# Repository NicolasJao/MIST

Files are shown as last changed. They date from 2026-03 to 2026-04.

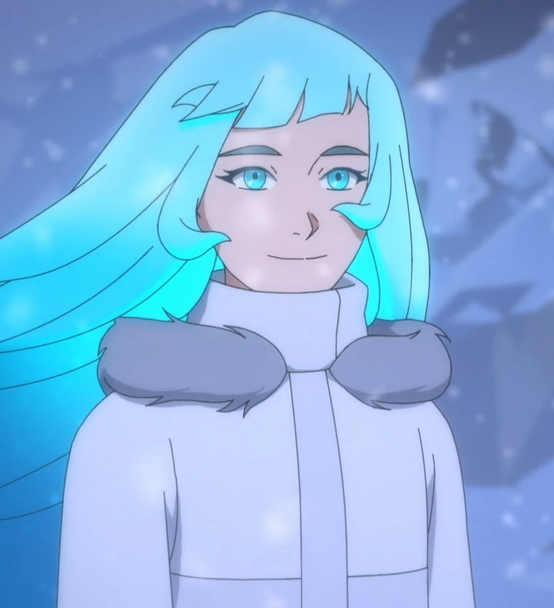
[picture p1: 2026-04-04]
RESOURCES/IMAGES/SILKSCREEN/MIST CI.png

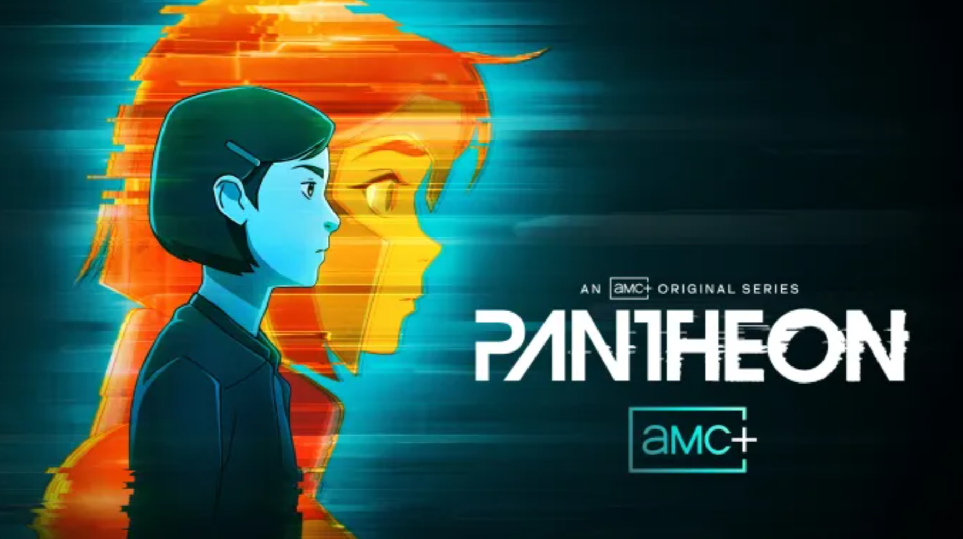
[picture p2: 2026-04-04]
RESOURCES/IMAGES/SILKSCREEN/Pantheon.png

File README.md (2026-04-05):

# MIST
4ES3 L02

Final project of SMRTTECH 4ES3 course.

A PCB project. Has an LED matrix that lights up in patterns based on music input from a microphone. Can make robot faces that makes expressions. Made with KiCad v9.0.

See /RESOURCES/IMAGES/3D VIEWER to see images of the PCB.
See /CODE to see the programming of the PCB.

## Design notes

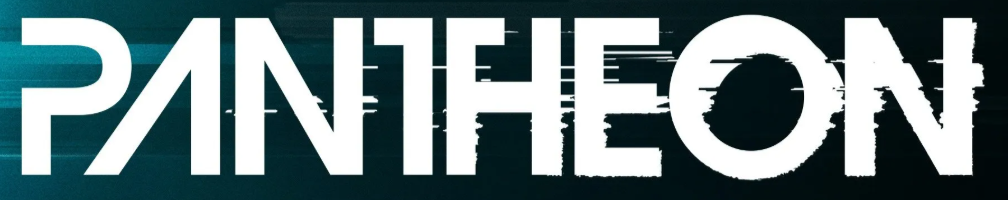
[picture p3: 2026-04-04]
RESOURCES/IMAGES/SILKSCREEN/Pantheon show.png

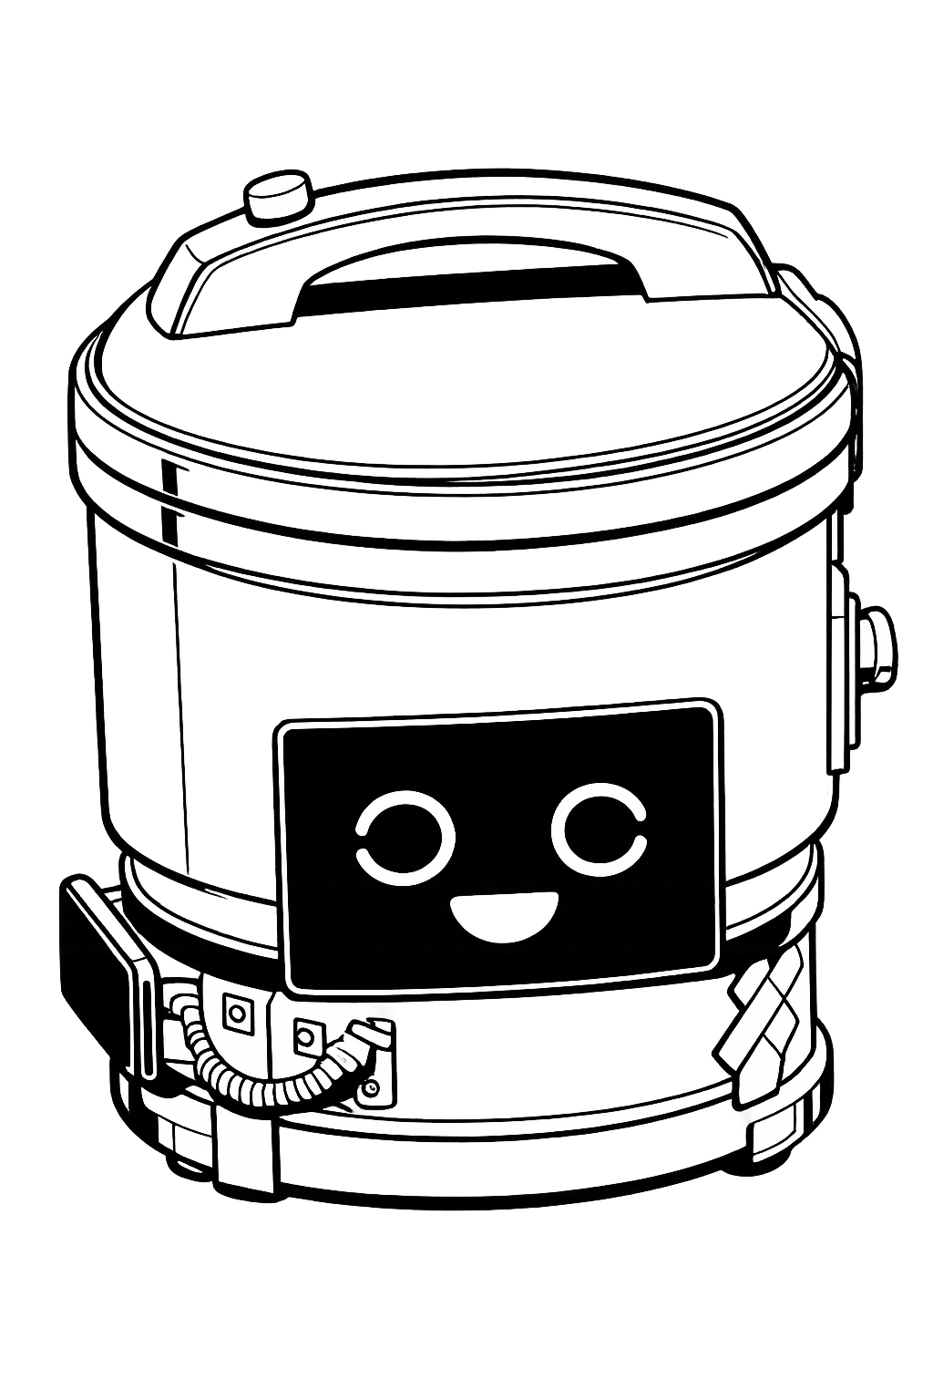
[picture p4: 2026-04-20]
RESOURCES/IMAGES/SILKSCREEN/MIST happy bitmap.png

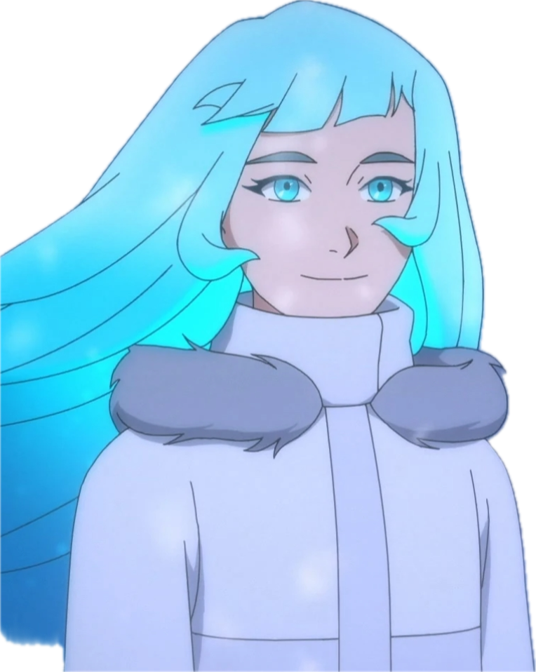
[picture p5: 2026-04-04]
RESOURCES/IMAGES/SILKSCREEN/MIST CI cropped.png

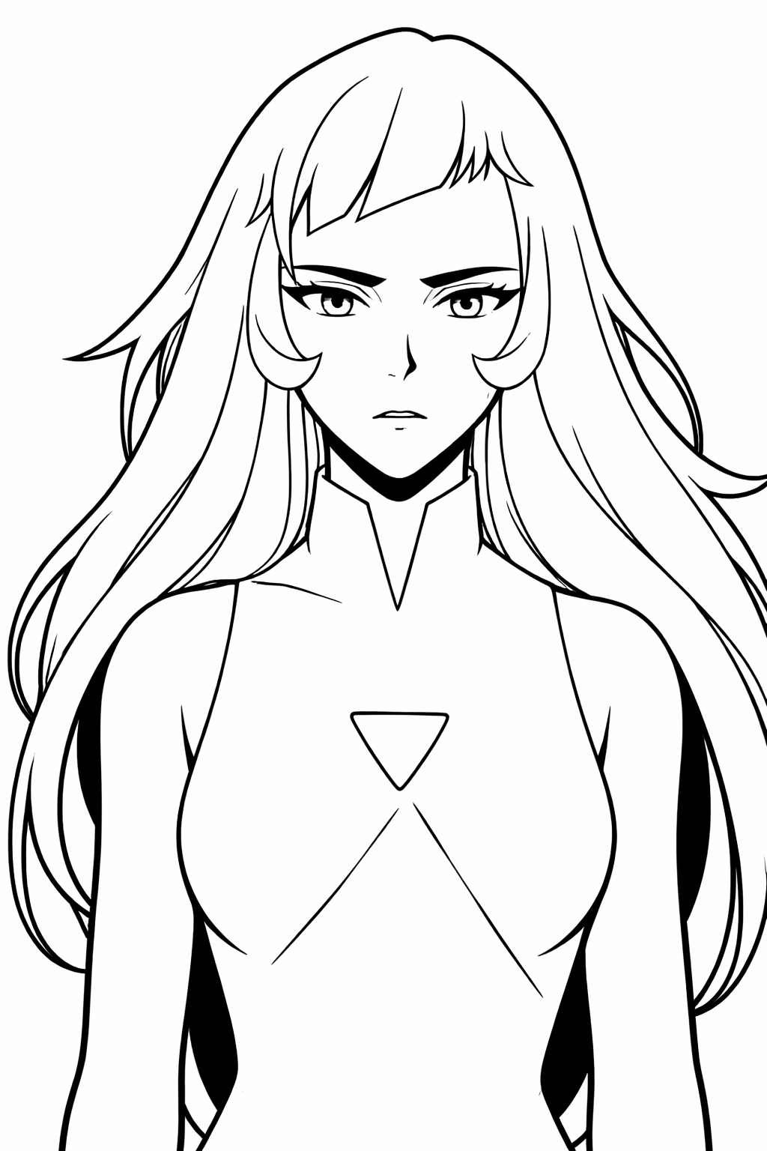
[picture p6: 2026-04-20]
RESOURCES/IMAGES/SILKSCREEN/MIST CI 2 bitmap.png

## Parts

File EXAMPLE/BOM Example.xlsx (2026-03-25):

Bill Of Material - Project Template
Item # | Designator | Description / Value | Manufacturer | Mounting Type | Package / Case | Unit Price | Quantity | Total | Link
1 | U1 | AtMega328PU | Atmel | SMT | 32-TQFP | $2.51 | 1 | $2.51 | https://www.digikey.ca/en/products/detail/microchip-technology/ATMEGA328PB-AU/5638812
2 | C1, C2 | 100nF Ceramic Capacitor | KEMET | SMT | 0805 (2012 Metric) | $0.26 | 2 | $0.52 | https://www.digikey.ca/en/products/detail/kemet/C0805C104J5RACAUTO/3314435
3 | C3, C4 | 22pF Ceramic Capacitor | Murata Electronics | SMT | 0805 (2012 Metric) | $0.35 | 2 | $0.70 | https://www.digikey.ca/en/products/detail/murata-electronics/GRM21A5C2D220JW01D/6606256
4 | C5 | 22uF Ceramic Capacitor | Murata Electronics | SMT | 0805 (2012 Metric) | $0.45 | 1 | $0.45 | https://www.digikey.ca/en/products/detail/murata-electronics/GRM21BZ70J226ME44K/19560602
5 | Y1 | 16Mhz Crystal Osillator | Abracon LLC | SMT | 4-SMD (3.2x2.5) | $1.05 | 1 | $1.05 | https://www.digikey.ca/en/products/detail/abracon-llc/ABM8-16.000MHZ-B2X-T/12349981
6 | R1, R2 | 10k Resistor | Würth Elektronik | SMT | 1206 (3216 Metric) | $0.29 | 2 | $0.58 | https://www.digikey.ca/en/products/detail/bourns-inc/CRM1206AJW-103ELF/8258196
7 | R3, R4, R5 | 220 Resistor | Bourns | SMT | 1206 (3216 Metric) | $0.18 | 3 | $0.54 | https://www.digikey.ca/en/products/detail/w-rth-elektronik/560112132015/24849722
8 | R6, R7 | 5.1K Resistor | Littlefuse | SMT | 1206 (3216 Metric) | $0.15 | 2 | $0.30 | https://www.digikey.ca/en/products/detail/bourns-inc/CR1206-JW-512ELF/3925471
9 | TH1 | 10K Thermoistor | YOCERA AVX | SMT | 1206 (3216 Metric) | $1.40 | 1 | $1.40 | https://www.digikey.ca/en/products/detail/littelfuse-inc./LR103G0J/3046801
10 | D1 | RGB LED | Kingbright | THT | 5MM LED | $0.99 | 1 | $0.99 | https://www.digikey.ca/en/products/detail/kingbright/WP154A4SUREQBFZGC/3084119
11 | J2 | USB Type C Power Only | Same Sky | SMT |  | $0.59 | 1 | $0.59 | https://www.digikey.ca/en/products/detail/same-sky-formerly-cui-devices/UJC-H-G-SMT-P6-TR/24818614
12 | S1 | Tactile Switch | Alpine | SMT |  | $0.32 | 1 | $0.32 | https://www.digikey.ca/en/products/detail/alps-alpine/SKRPABE010/18768948
 |  |  |  |  |  |  | Total: | $9.95

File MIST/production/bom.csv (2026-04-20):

Designator | Footprint | Quantity | Value | LCSC Part #
C1, C2 | 0805 | 2 | 100n
C3, C4 | 0805 | 2 | 22pF
C5 | 0805 | 1 | 22uF
C6, C8, C9 | 0805 | 3 | 0.1u
C7 | 0805 | 1 | 0.1n
J1, J2 | PinHeader_1x08_P2.54mm_Vertical | 2 | Conn_01x08
J3 | USB_C_Receptacle_GCT_USB4125-xx-x_6P_TopMnt_Horizontal | 1 | USB_C_Receptacle_PowerOnly_6P
J4 | PinHeader_2x03_P2.54mm_Vertical | 1 | ICSP
MK1 | CUI_CMC-5042PF-AC | 1 | CMC-5042PF-AC
R1, R2, R3 | 0805 | 3 | 10k
R10 | 0805 | 1 | 100k
R4, R5 | 0805 | 2 | 5.1k
R6, R7 | 0805 | 2 | 2k
R8, R9 | 0805 | 2 | 1M
S1, S2 | SW_SKRPABE010 | 2 | SKRPABE010
U1 | TQFP-32_7x7mm_P0.8mm | 1 | ATmega328PB-A
U2 | SOIC-24W_7.5x15.4mm_P1.27mm | 1 | MAX7219
U3 | SOT65P210X110-5N | 1 | MAX4466EXK
Y1 | Crystal_SMD_3225-4Pin_3.2x2.5mm | 1 | 16 Mhz Crystal

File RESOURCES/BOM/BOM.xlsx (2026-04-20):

Bill Of Material - Project Template
Item # | Designator | Description / Value | Manufacturer | Mounting Type | Package / Case | Unit Price | Quantity | Total | Link
1 | U1 | AtMega328PB | Atmel | SMT | 32-TQFP | $2.51 | 1 | $2.51 | https://www.digikey.ca/en/products/detail/microchip-technology/ATMEGA328PB-AU/5638812
2 | C1, C2 | 100nF Ceramic Capacitor | KEMET | SMT | 0805 (2012 Metric) | $0.26 | 2 | $0.52 | https://www.digikey.ca/en/products/detail/kemet/C0805C104J5RACAUTO/3314435
3 | C3, C4 | 22pF Ceramic Capacitor | Murata Electronics | SMT | 0805 (2012 Metric) | $0.35 | 2 | $0.70 | https://www.digikey.ca/en/products/detail/murata-electronics/GRM21A5C2D220JW01D/6606256
4 | C5 | 22uF Ceramic Capacitor | Murata Electronics | SMT | 0805 (2012 Metric) | $0.45 | 1 | $0.45 | https://www.digikey.ca/en/products/detail/murata-electronics/GRM21BZ70J226ME44K/19560602
5 | Y1 | 16Mhz Crystal Osillator | Abracon LLC | SMT | 4-SMD (3.2x2.5) | $1.05 | 1 | $1.05 | https://www.digikey.ca/en/products/detail/abracon-llc/ABM8-16.000MHZ-B2X-T/12349981
6 | R1, R2, R3 | 10k Resistor | Stackpole Electronics Inc | SMT | 0805 (2012 Metric) | $0.15 | 10 | $1.50 | https://www.digikey.ca/en/products/detail/stackpole-electronics-inc/RMCF0805FT10K0/1760676
7 | R4, R5 | 5.1K Resistor | Stackpole Electronics Inc | SMT | 0805 (2012 Metric) | $0.16 | 2 | $0.32 | https://www.digikey.ca/en/products/detail/stackpole-electronics-inc/RMCF0805JT5K10/1757930
8 | J2 | USB Type C Power Only | Same Sky | SMT |  | $0.59 | 1 | $0.59 | https://www.digikey.ca/en/products/detail/same-sky-formerly-cui-devices/UJC-H-G-SMT-P6-TR/24818614
9 | S1, S2 | Tactile Switch | Alpine | SMT |  | $0.32 | 10 | $3.20 | https://www.digikey.ca/en/products/detail/alps-alpine/SKRPABE010/18768948
10 | U2 | LED Driver 24-SOIC | Analog Devices Inc./Maxim Integrated | SMT | 24-SOIC (0.295", 7.50mm Width) | $27.91 | 1 | $27.91 | https://www.digikey.ca/en/products/detail/analog-devices-inc-maxim-integrated/MAX7219CWG-T/1514450
11 | C6, C7, C8, C9 | 0.1uF Ceramic Capacitor | KEMET | SMT | 0805 (2012 Metric) | $0.12 | 10 | $1.20 | https://www.digikey.ca/en/products/detail/kemet/C0805C104K5RACTU/411169
12 | MK1 | Microphone | Same Sky | THT |  | $1.89 | 3 | $5.67 | https://www.digikey.ca/en/products/detail/same-sky-formerly-cui-devices/CMC-5042PF-AC/1869984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
13 | U3 | Microphone Preamplifier | Analog Devices Inc./Maxim Integrated | SMT | 5-TSSOP, SC-70-5, SOT-353 | $1.51 | 3 | $4.53 | https://www.digikey.ca/en/products/detail/analog-devices-inc-maxim-integrated/MAX4466EXK-T/1781624
14 | R6, R7 | 2k Resistor | Panasonic Electronic Components | SMT | 0805 (2012 Metric) | $0.15 | 5 | $0.75 | https://www.digikey.ca/en/products/detail/panasonic-electronic-components/ERA-6AEB202V/1465756
15 | R8, R9 | 1M Resistor | Panasonic Electronic Components | SMT | 0805 (2012 Metric) | $0.15 | 5 | $0.75 | https://www.digikey.ca/en/products/detail/panasonic-electronic-components/ERJ-3EKF1004V/196033
16 | R10 | 100k Resistor | Panasonic Electronic Components | SMT | 0805 (2012 Metric) | $0.15 | 5 | $0.75 | https://www.digikey.ca/en/products/detail/panasonic-electronic-components/ERA-6AEB104V/1465797
17 |  | 8x8 LED Matrix | On Hand | THT | Custom | $0.00 | 1 | $0.00 | On Hand
 |  |  |  |  |  |  | Total: | $52.40

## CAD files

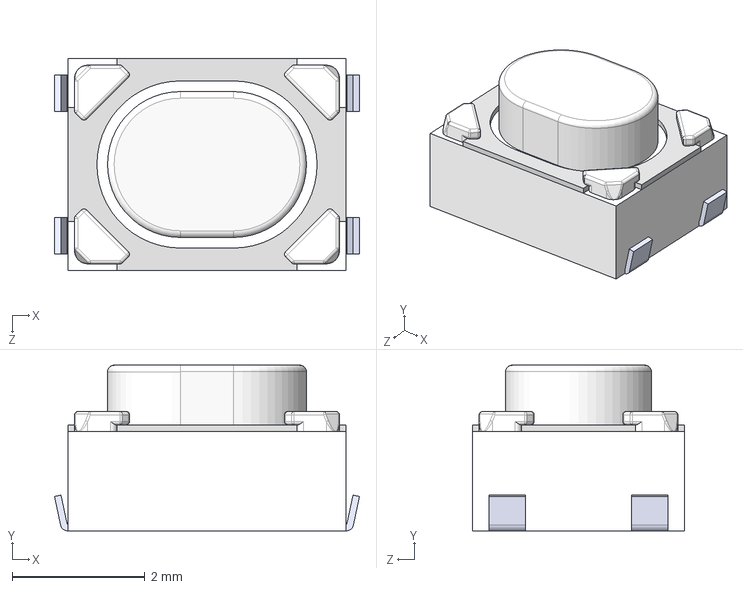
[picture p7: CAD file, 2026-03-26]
EXAMPLE/EXAMPLE/SKRPABE010/SKRPABE010.step
4.60 x 2.50 x 3.20 mm

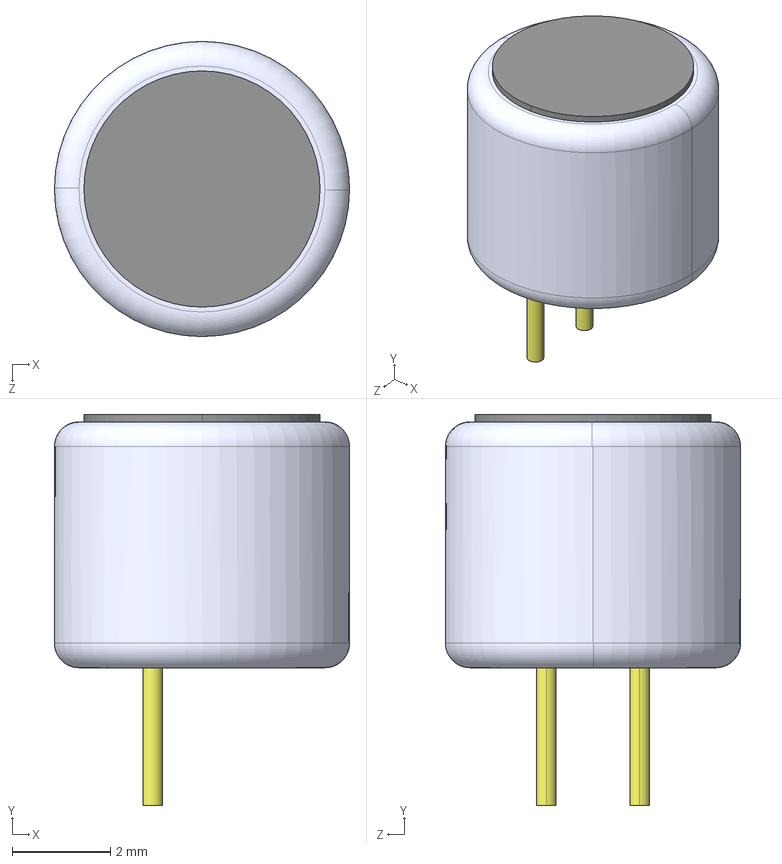
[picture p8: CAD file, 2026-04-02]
MIST/CMC-5042PF-AC/CMC-5042PF-AC.step
6.00 x 7.95 x 6.00 mm

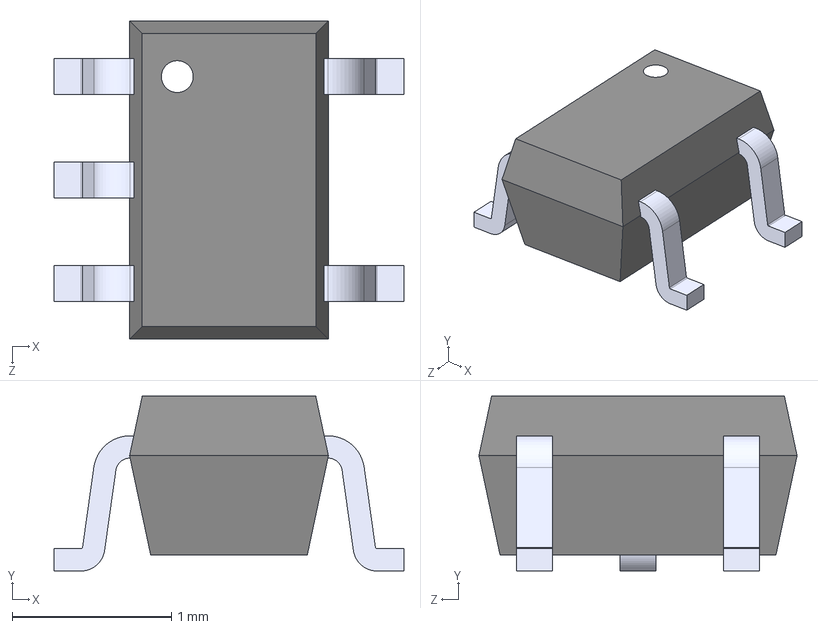
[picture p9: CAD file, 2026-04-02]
MIST/MAX4466EXK/MAX4466EXK.step
2.20 x 1.10 x 2.00 mm

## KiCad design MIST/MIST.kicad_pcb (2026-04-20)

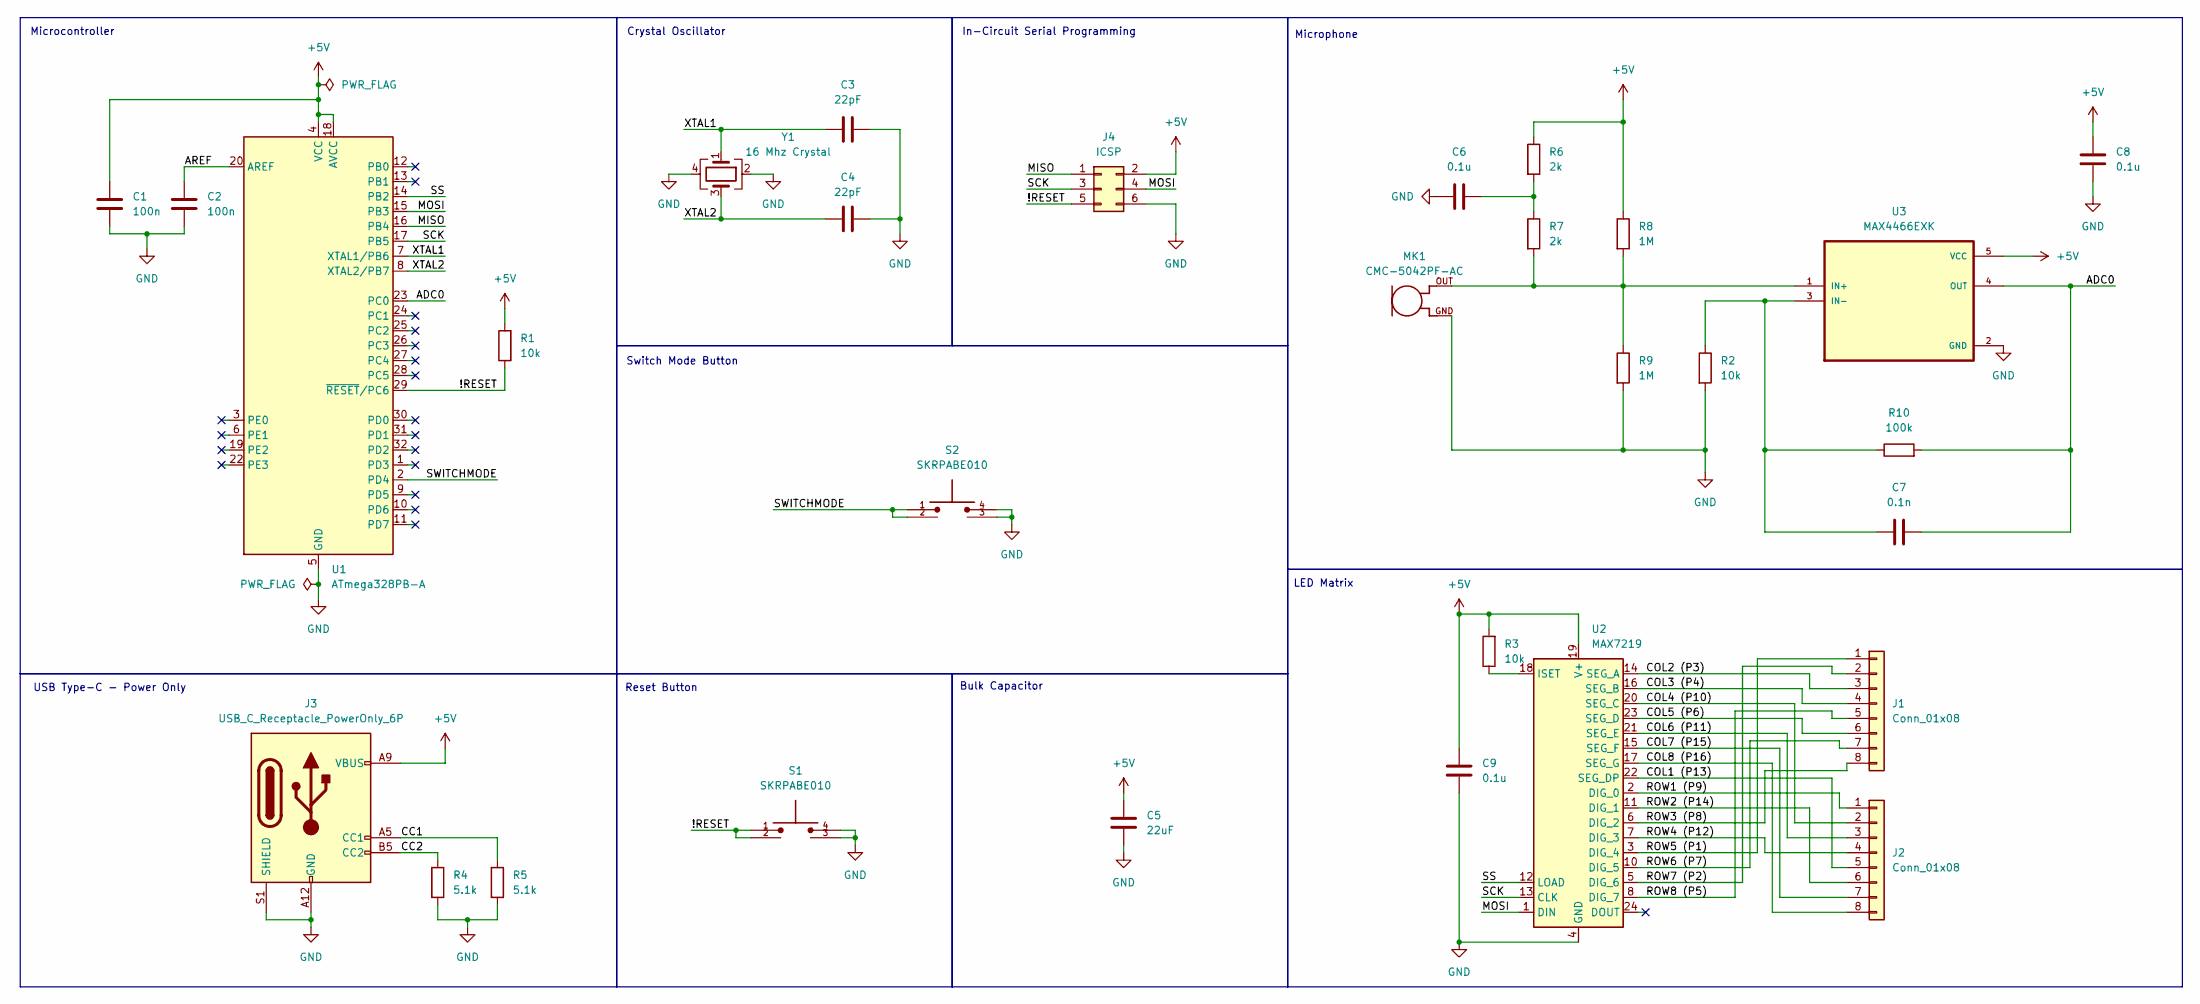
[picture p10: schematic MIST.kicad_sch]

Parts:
C1, C2: 100n; C_0805_2012Metric
C3, C4: 22pF; C_0805_2012Metric
C5: 22uF; C_0805_2012Metric
C6, C8, C9: 0.1u; C_0805_2012Metric
C7: 0.1n; C_0805_2012Metric
J1, J2: Conn_01x08; PinHeader_1x08_P2.54mm_Vertical
J3: USB_C_Receptacle_PowerOnly_6P; USB_C_Receptacle_GCT_USB4125-xx-x_6P_TopMnt_Horizontal
J4: ICSP; PinHeader_2x03_P2.54mm_Vertical
MK1: CMC-5042PF-AC; CUI_CMC-5042PF-AC
R1, R2: 10k; R_0805_2012Metric
R3: 10k; C_0805_2012Metric
R4, R5: 5.1k; C_0805_2012Metric
R6, R7: 2k; R_0805_2012Metric
R8, R9: 1M; R_0805_2012Metric
R10: 100k; R_0805_2012Metric
S1, S2: SKRPABE010; SW_SKRPABE010
U1: ATmega328PB-A; TQFP-32_7x7mm_P0.8mm
U2: MAX7219; SOIC-24W_7.5x15.4mm_P1.27mm
U3: MAX4466EXK; SOT65P210X110-5N
Y1: 16 Mhz Crystal; Crystal_SMD_3225-4Pin_3.2x2.5mm

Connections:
+5V: C1.2, C5.2, C8.1, C9.1, J3.A9 (VBUS), J3.B9 (VBUS), J4.2, R1.2, R3.2, R6.1, R8.1, U1.4 (VCC), U1.18 (AVCC), U2.19 (V+), U3.5 (VCC)
/!RESET: J4.5, R1.1, S1.1, S1.2, U1.29 (~RESET/PC6)
/ADC0: C7.2, R10.2, U1.23 (PC0), U3.4 (OUT)
/AREF: C2.2, U1.20 (AREF)
/CC1: J3.A5 (CC1), R5.1
/CC2: J3.B5 (CC2), R4.1
/COL1 (P13): J2.5, U2.22 (SEG_DP)
/COL2 (P3): J1.3, U2.14 (SEG_A)
/COL3 (P4): J1.4, U2.16 (SEG_B)
/COL4 (P10): J2.2, U2.20 (SEG_C)
/COL5 (P6): J1.6, U2.23 (SEG_D)
/COL6 (P11): J2.3, U2.21 (SEG_E)
/COL7 (P15): J2.7, U2.15 (SEG_F)
/COL8 (P16): J2.8, U2.17 (SEG_G)
/MISO: J4.1, U1.16 (PB4)
/MOSI: J4.4, U1.15 (PB3), U2.1 (DIN)
/ROW1 (P9): J2.1, U2.2 (DIG_0)
/ROW2 (P14): J2.6, U2.11 (DIG_1)
/ROW3 (P8): J1.8, U2.6 (DIG_2)
/ROW4 (P12): J2.4, U2.7 (DIG_3)
/ROW5 (P1): J1.1, U2.3 (DIG_4)
/ROW6 (P7): J1.7, U2.10 (DIG_5)
/ROW7 (P2): J1.2, U2.5 (DIG_6)
/ROW8 (P5): J1.5, U2.8 (DIG_7)
/SCK: J4.3, U1.17 (PB5), U2.13 (CLK)
/SS: U1.14 (PB2), U2.12 (LOAD)
/SWITCHMODE: S2.1, S2.2, U1.2 (PD4)
/XTAL1: C3.1, U1.7 (XTAL1/PB6), Y1.1
/XTAL2: C4.2, U1.8 (XTAL2/PB7), Y1.3
GND: C1.1, C2.1, C3.2, C4.1, C5.1, C6.1, C8.2, C9.2, J3.A12 (GND), J3.B12 (GND), J3.S1 (SHIELD), J4.6, MK1.GND, R2.2, R4.2, R5.2, R9.2, S1.3, S1.4, S2.3, S2.4, U1.5 (GND), U1.21 (GND), U2.4 (GND), U2.9 (GND), U3.2 (GND), Y1.2, Y1.4
unnamed: C6.2, R6.2, R7.1
unnamed: R3.1, U2.18 (ISET)
unnamed: MK1.OUT, R7.2, R8.2, R9.1, U3.1 (IN+)
unnamed: C7.1, R2.1, R10.1, U3.3 (IN-)

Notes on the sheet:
Bulk Capacitor
Switch Mode Button
LED Matrix
USB Type-C - Power Only
In-Circuit Serial Programming
Microcontroller
Reset Button
Crystal Oscillator
Microphone

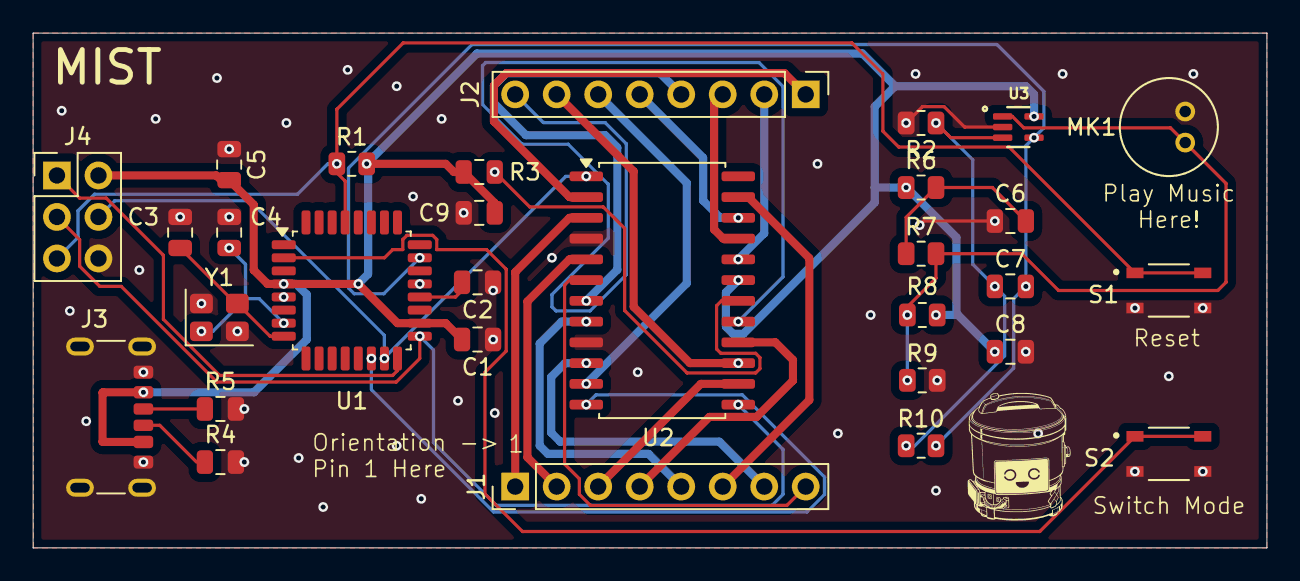
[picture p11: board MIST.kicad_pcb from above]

Board: 2 copper layers, 75.5 x 31.5 mm, 30 parts (0 on the bottom side), 34 nets.

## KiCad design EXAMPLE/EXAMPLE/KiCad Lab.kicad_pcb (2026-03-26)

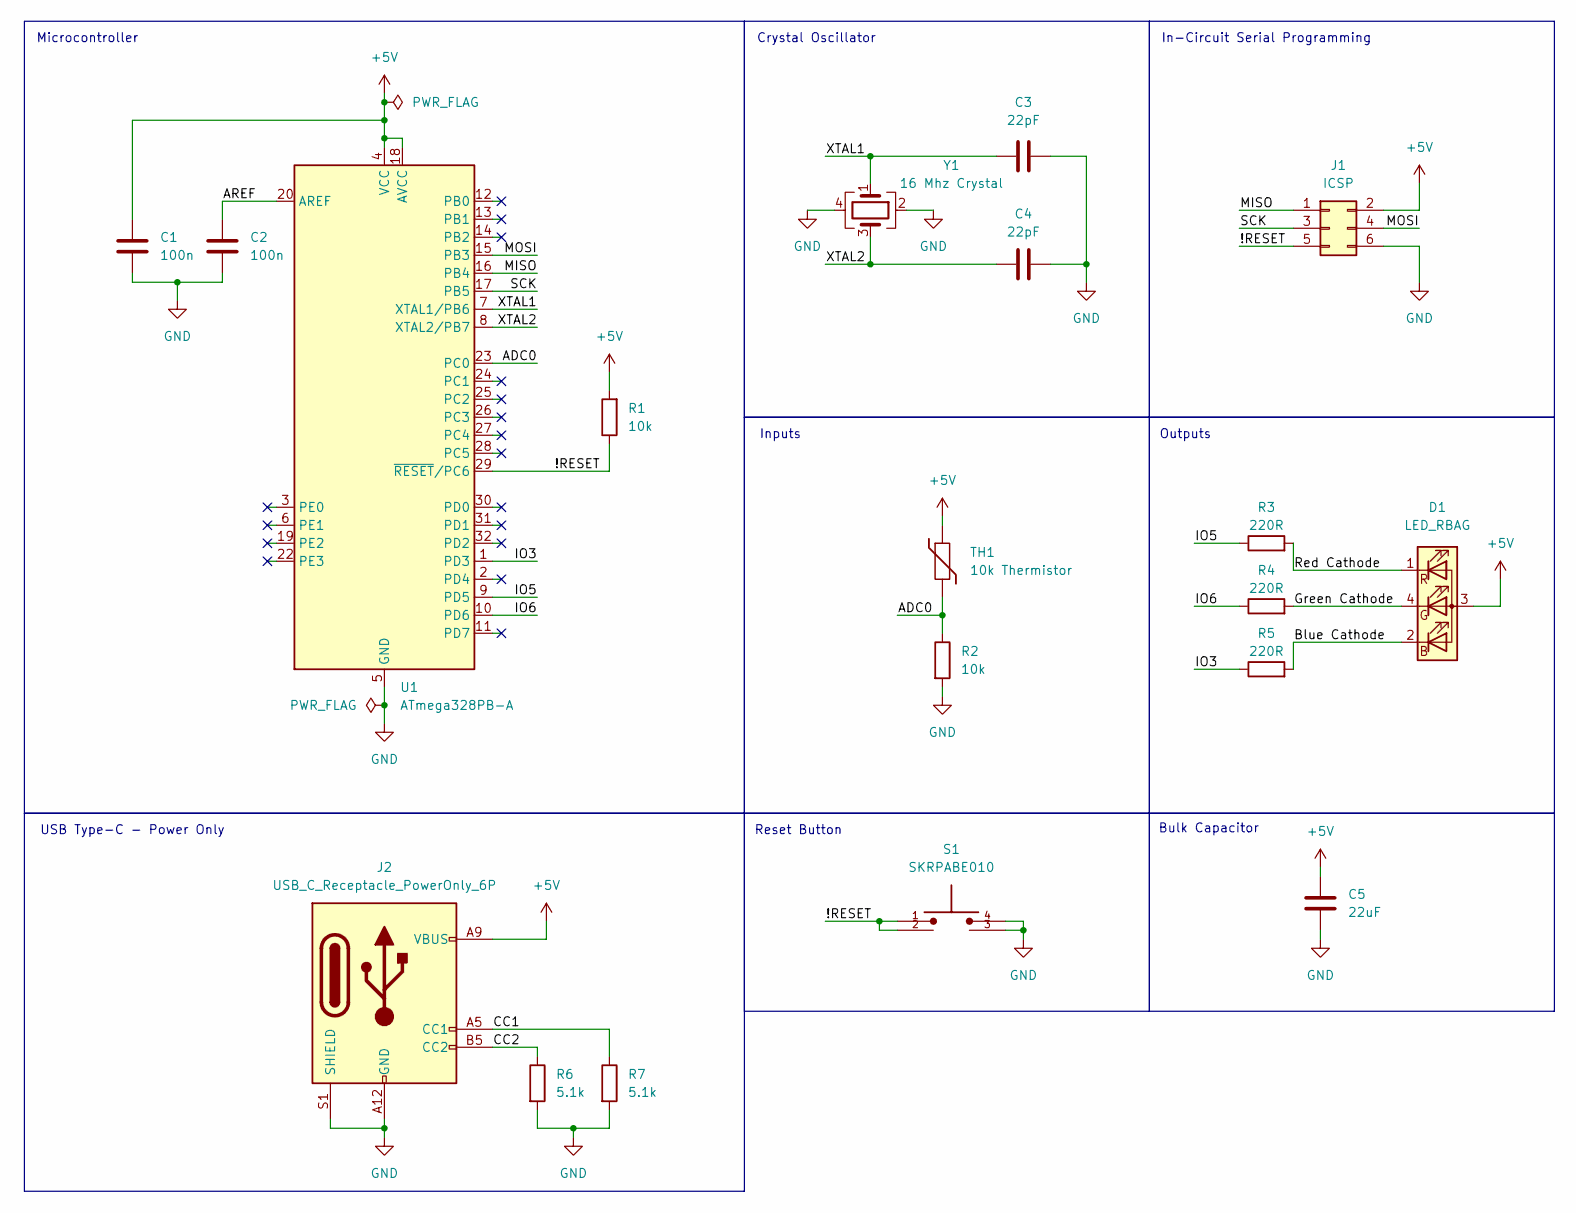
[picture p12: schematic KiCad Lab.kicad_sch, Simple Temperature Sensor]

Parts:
C1, C2: 100n; C_0805_2012Metric
C3, C4: 22pF; C_0805_2012Metric
C5: 22uF; C_0805_2012Metric
D1: LED_RBAG; LED_D5.0mm-4_RGB_Wide_Pins
J1: ICSP; PinHeader_2x03_P2.54mm_Vertical
J2: USB_C_Receptacle_PowerOnly_6P; USB_C_Receptacle_GCT_USB4125-xx-x_6P_TopMnt_Horizontal
R1, R2: 10k; R_1206_3216Metric
R3, R4, R5: 220R; R_1206_3216Metric
R6, R7: 5.1k; R_1206_3216Metric
S1: SKRPABE010; SW_SKRPABE010
TH1: 10k Thermistor; R_1206_3216Metric
U1: ATmega328PB-A; TQFP-32_7x7mm_P0.8mm
Y1: 16 Mhz Crystal; Crystal_SMD_3225-4Pin_3.2x2.5mm

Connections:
+5V: C1.2, C5.2, D1.3 (A), J1.2, J2.A9 (VBUS), J2.B9 (VBUS), R1.2, TH1.1, U1.4 (VCC), U1.18 (AVCC)
/!RESET: J1.5, R1.1, S1.1, S1.2, U1.29 (~RESET/PC6)
/ADC0: R2.1, TH1.2, U1.23 (PC0)
/AREF: C2.2, U1.20 (AREF)
/Blue Cathode: D1.2 (BK), R5.2
/CC1: J2.A5 (CC1), R7.1
/CC2: J2.B5 (CC2), R6.1
/Green Cathode: D1.4 (GK), R4.2
/IO3: R5.1, U1.1 (PD3)
/IO5: R3.1, U1.9 (PD5)
/IO6: R4.1, U1.10 (PD6)
/MISO: J1.1, U1.16 (PB4)
/MOSI: J1.4, U1.15 (PB3)
/Red Cathode: D1.1 (RK), R3.2
/SCK: J1.3, U1.17 (PB5)
/XTAL1: C3.1, U1.7 (XTAL1/PB6), Y1.1
/XTAL2: C4.2, U1.8 (XTAL2/PB7), Y1.3
GND: C1.1, C2.1, C3.2, C4.1, C5.1, J1.6, J2.A12 (GND), J2.B12 (GND), J2.S1 (SHIELD), R2.2, R6.2, R7.2, S1.3, S1.4, U1.5 (GND), U1.21 (GND), Y1.2, Y1.4

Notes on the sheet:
Inputs
In-Circuit Serial Programming
USB Type-C - Power Only
Microcontroller
Bulk Capacitor
Reset Button
Crystal Oscillator
Outputs

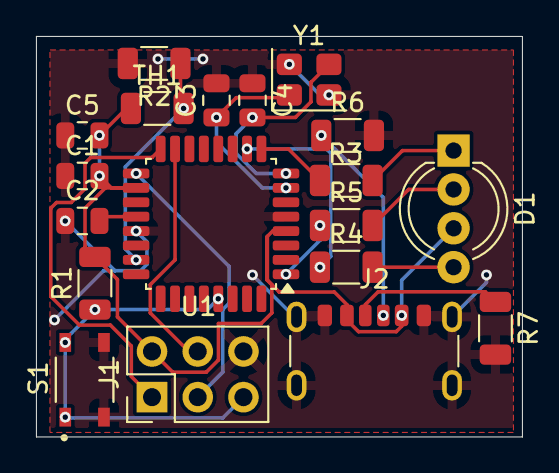
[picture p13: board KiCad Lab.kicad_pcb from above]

Board: 2 copper layers, 27.0 x 22.2 mm, 19 parts (0 on the bottom side), 18 nets.

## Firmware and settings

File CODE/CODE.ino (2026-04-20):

#include <LedControl.h>
#include <avr/wdt.h>

#define MIC_PIN A0
#define THRESHOLD 100000  // adjust this up or down based on your mic sensitivity 513

LedControl lc = LedControl(/*DIN=*/11, /*CLK=*/13, /*CS=*/10, /*numDevices=*/1);

void setAll(bool on) {
  byte val = on ? B11111111 : B00000000;
  for (int row = 0; row < 8; row++) {
    lc.setRow(0, row, val);
  }
}

void setup() {
  wdt_disable();
  delay(500);
  lc.shutdown(0, false);
  lc.setIntensity(0, 8);
  lc.clearDisplay(0);
}

void loop() {
  int sample = analogRead(MIC_PIN);
  int centered = abs(sample - 512);

  if (centered > THRESHOLD) {
    // sound detected - stop blinking, turn full board on
    setAll(true);
  } else {
    // no sound - blink
    setAll(true);
    delay(100);
    setAll(false);
    delay(100);
  }
}

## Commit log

2026-03-08 did some stuff
    [MIST.kicad_pcb, MIST.kicad_sch, bom.csv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]
2026-03-25 changed folder structure
    [MIST.kicad_pcb, MIST.kicad_sch, bom.csv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]
2026-03-25 added a bunch of resources
    [BOM Example.xlsx]
2026-03-26 did stuff
    [BOM Example.xlsx, BOM.xlsx, KiCad Lab.kicad_pcb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]
2026-03-29 finished BOM and added resources and started layout
    [BOM.xlsx, MIST.kicad_pcb, MIST.kicad_sch]
2026-03-29 closed KiCad lol
2026-04-02 finished schematic. updated BOM. stuff.
    [BOM.xlsx, CMC-5042PF-AC.step, MAX4466EXK.step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]
2026-04-04 finished schematic and layout
    [BOM.xlsx, MIST.kicad_pcb, MIST.kicad_sch]
2026-04-04 added GND planes to both layers and via stitched
    [MIST.kicad_pcb, bom.csv, designators.csv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]
2026-04-20 fixed wrong matrix pin mappings schematic.
    [BOM.xlsx, MIST.kicad_pcb, MIST.kicad_sch]
2026-04-20 fixed matrix pin mappings on layout. updated bitmap silkscreens.
    [MIST.kicad_pcb, bom.csv, positions.csv]
